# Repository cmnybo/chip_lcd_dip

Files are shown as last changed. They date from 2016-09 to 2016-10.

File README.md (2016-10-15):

# C.H.I.P. LCD Adapter & SPI Multiplexer

This DIP is compatible with the following touch screen LCD panels (resistive touch version only):

1. [4.3" 480x272](http://www.buydisplay.com/default/tft-4-3-inch-lcd-module-touchscreen-display-for-mp4-gps-480x272)
2. [5" 800x480](http://www.buydisplay.com/default/5-tft-lcd-display-module-wvga-800x480-high-resolution-for-mp4-gps)
3. [7" 800x480](http://www.buydisplay.com/default/7-tft-lcd-touch-screen-display-module-800x480-for-mp4-gps-tablet-pc)

## Features

* PWM controlled backlight driver
* 8 channel chip select multiplexer for SPI
* 34 pin gpio header that can be connected with old floppy drive cables
* Pin headers for the UART and power switch
* 5.5x2.5mm barrel jack to supply power (5V 2.5A)

The original design files for this board were created in [KiCAD](http://kicad-pcb.org/). <br/>
There are PDF copies of the schematic, PCB layout, and bill of materials in the "pdf" directory.<br/>
The "gerber" directory contains all of the files needed to have some boards made.<br/>
The device tree overlay, kernel patch, and EEPROM image are in the "source" directory.

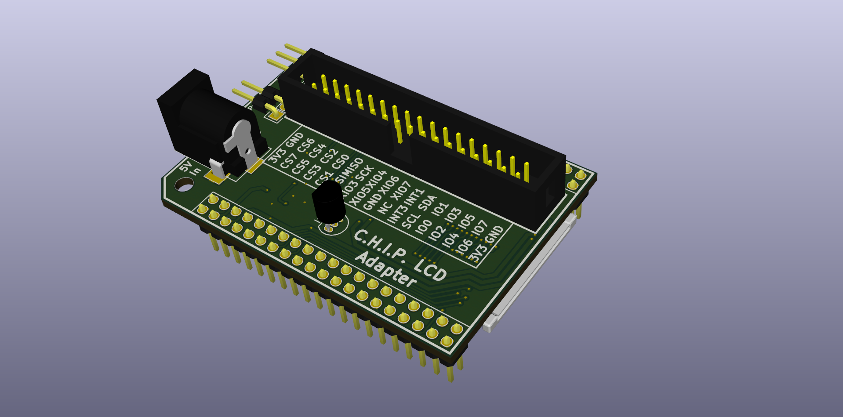
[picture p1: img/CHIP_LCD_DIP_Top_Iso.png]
3D Rendering of the DIP


## License
**This project is open source hardware.**

All files are licensed under a [Creative Commons Attribution-ShareAlike](https://creativecommons.org/licenses/by-sa/3.0) license.



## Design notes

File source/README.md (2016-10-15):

# Software

## Files
* lcd_panel.dts The device tree overlay source for this DIP
* dip-d653-1.dtbo The compiled device tree overlay for this dip
* er-tft050-3.patch The patch for the kernel driver to support the 5" & 7" LCDs
* lcd.img The EEPROM image for the DIP
* Linux_Kernel_4.4.11_Patched.tar.gz My custom kernel with the LCD patch already installed
* bl.sh A bash script to control the LCD backlight

## Installation
1. Install the patched kernel. 
2. Install the DTBO file. Run "`cp dip-d653-1.dtbo /lib/firmware/nextthingco/chip/early/`"
3. Flash lcd.img to the EEPROM. Run "`cat lcd.img > /sys/bus/w1/devices/2d-*/eeprom`"
4. Reboot C.H.I.P. It takes several seconds for the LCD to come on.
5. Calibrate the touch screen. 

## Touch Screen Calibration
You will probably need to connect a mouse until the tough screen is calibrated.<br/>
Install xinput_calibrator.<br/>
Run "`mkdir -p /etc/X11/xorg.conf.d/`" to create the directory for the calibration data.<br/>
Select "System > Calibrate Touchscreen" from the applications menu. <br/>
Follow the instructions, then paste its output in `/etc/X11/xorg.conf.d/99-calibration.conf`<br/>
Reboot or run "`systemctl restart lightdm`" to restart the X server.

You can add the following lines to the calibration file to enable right click emulation.<br/>
>
`Option	"EmulateThirdButton" "1"`<br/>
`Option	"EmulateThirdButtonTimeout" "750"`<br/>
`Option	"EmulateThirdButtonMoveThreshold" "30"`<br/>

## Controlling the backlight
Put the bl.sh script in a directory that's included in your $PATH variable.<br/>
Run `bl.sh` with the `--up` or `--dn` options to adjust the brightness.<br/>
Run `bl.sh` with the `--toggle` option to toggle the display on and off.<br/>
For easier control, you can add these to some shortcuts in the 
"Application Shortcuts" tab of the Keyboard settings window.

The system power management can automatically turn off the display when idle, 
but I have noticed some problems when turning the screen back on. If you have 
trouble with this, you can disable power management for the LCD in the 
"Power Manager" window.

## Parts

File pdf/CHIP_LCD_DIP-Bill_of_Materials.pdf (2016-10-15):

Bill of Materials

Page 1

Reference | Value | Manufacturer | Package | DigiKey | Quantity Notes
C1, C2, C7 | 0.1µF | Samsung | 0603 | 1276-1006-1-ND | 3
C3 | 1µF | Samsung | 0603 | 1276-6524-1-ND | 1
C4 | 10µF | Samsung | 0603 | 1276-1119-1-ND | 1
C5 | 10µF | Samsung | 0805 | 490-12538-1-ND | 1
C6 | 1µF | Samsung | 0603 | 1276-1860-1-ND | 1 Can be used for C3 as well
D1 | DB2J40700 Panasonic | SOD-323 | DB2J40700LCT-ND | 1
IC1 | 74LVC138 | NXP Semiconductors | 16-SOIC (3.90mm) 568-1577-5-ND | 1
IC2 | DS2431 | Maxim Integrated | TO-92-3 | DS2431+-ND | 1
IC3 | AP3032 | Diodes Incorporated | SOT-23-6 | AP3032KTR-G1DICT-ND | 1
IC4 | 74AHC1G08 NXP Semiconductors | SC-70-5 | 568-2501-1-ND | 1
L1 | 15µH | TDK | | 445-6598-1-ND | 1
P1 | C.H.I.P. | Sullins Connector Solutions | | S2011EC-20-ND | 220x2 Pin Male Headers
P2 | Power | CUI Inc. | 2.5x5.5mm | CP-002B-ND | 15.5x2.5mm Barrel Jack
P3 | Pwr SW | Harwin Inc. | | 952-2244-ND | 12 Pin Male Header (Right Angle)
P4 | UART | Harwin Inc. | | 952-2245-ND | 13 Pin Male Header (Right Angle)
P5 | LCD | TE Connectivity | | A100226CT-ND | 140 Pin Flat Flex 0.5mm Bottom Contacts
P6 | GPIO | On Shore Technology Inc. | | ED10528-ND | 117x2 Shrouded Male Header
R1 | 5.1Ω | Yageo | 0603 | 311-5.1GRCT-ND | 1 For 5” & 7” Panels (39mA backlight)
R1 | 15Ω | Yageo | 0603 | 311-15GRCT-ND | 1 For 4.3” Panel (13mA Backlight)
R2 | 4.7K | Yageo | 0603 | 311-4.7KGRCT-ND | 1

Notes
Capacitors can be substituted as long as the package, voltage, and capacitance is the same. Use X5R or X7R dielectric. Resistors can be substituted as long as the package and resistance are the same.
Cheap pin headers from eBay will work fine if you want to save some money. DigiKey is expensive for pin headers.
The LCD connector (P5) is already installed if you bought one of my boards.

R1 sets the backlight current. Current = 0.2/R1

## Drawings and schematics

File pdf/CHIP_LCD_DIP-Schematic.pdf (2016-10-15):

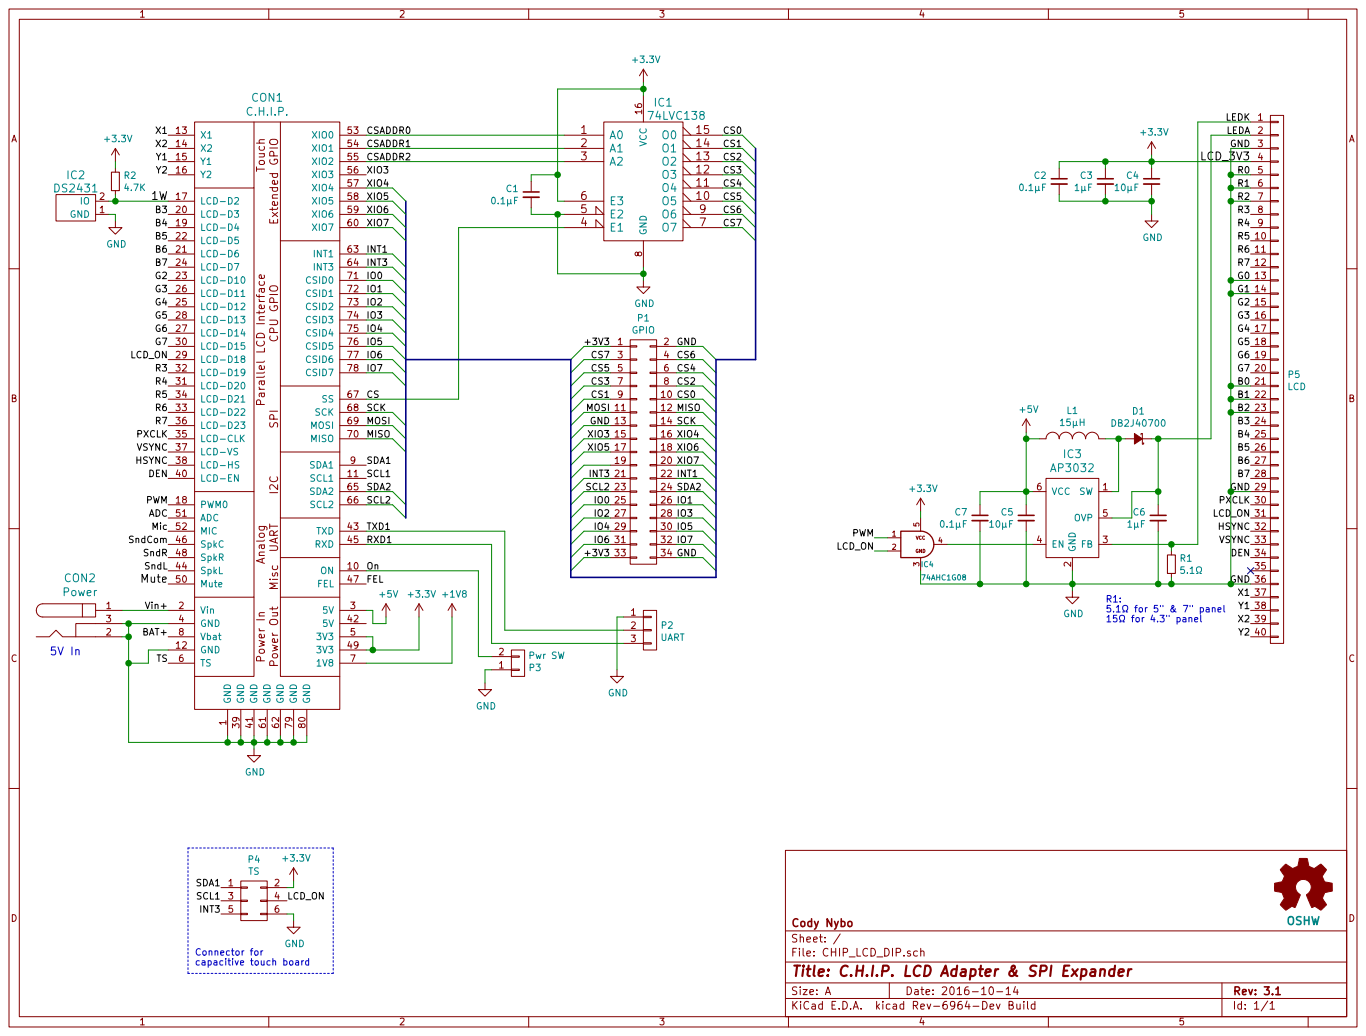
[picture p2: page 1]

File: CHIP_LCD_DIP.sch Sheet: / Cody Nybo Analog CPU GPIO Extended GPIO I2C Misc Parallel LCD Interface Power In Power Out SPI Touch UART GND

DEN
Vin+ PWM
ADC Mic SndL SndR

2 FB 3 EN 4 OVP 5 VCC 6

Connector for capacitive touch board

Id: 1/1 Title: C.H.I.P. LCD Adapter & SPI Expander

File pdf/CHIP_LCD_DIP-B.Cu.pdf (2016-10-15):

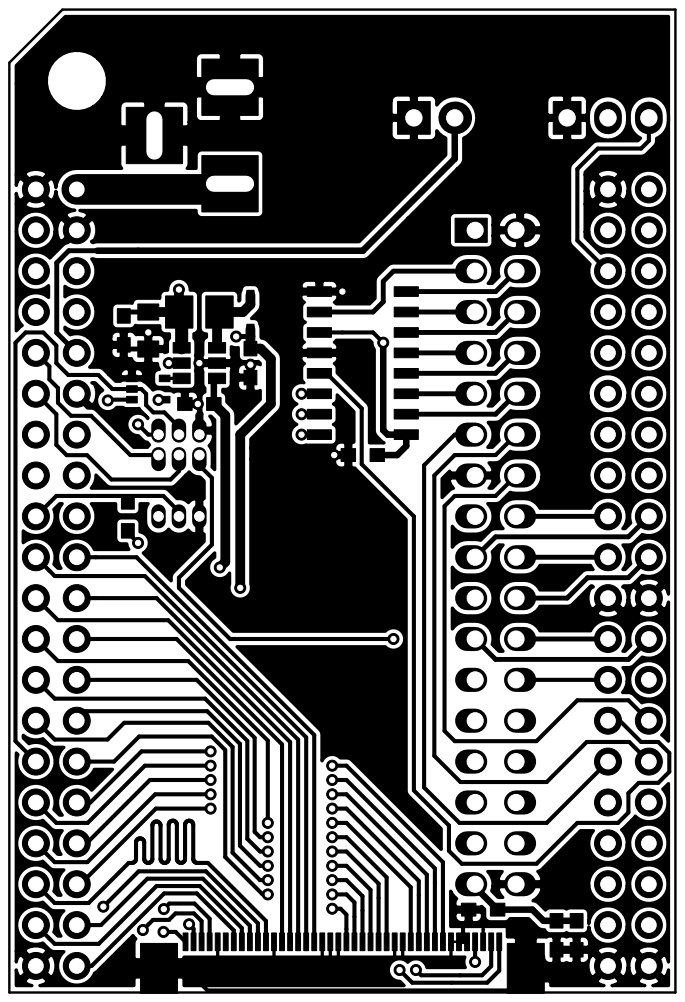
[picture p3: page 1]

File: CHIP_LCD_DIP.kicad_pcb Sheet: Cody Nybo

Id: 1/1 Title: C.H.I.P. LCD Adapter & SPI Expander

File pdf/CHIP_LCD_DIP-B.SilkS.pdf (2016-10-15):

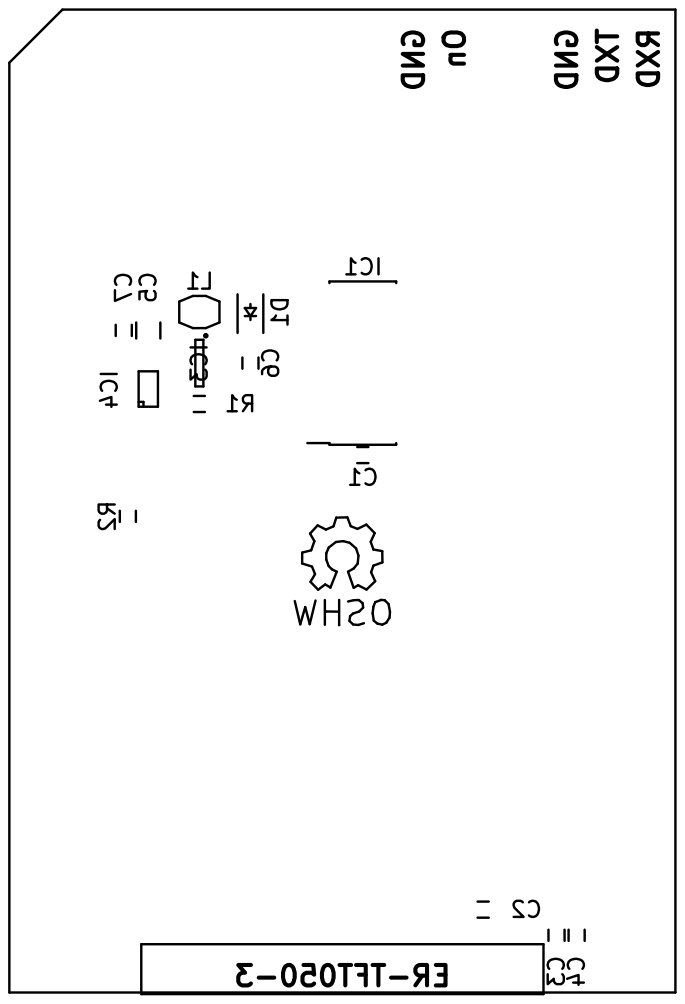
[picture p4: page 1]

Id: 1/1 Title: C.H.I.P. LCD Adapter & SPI Expander

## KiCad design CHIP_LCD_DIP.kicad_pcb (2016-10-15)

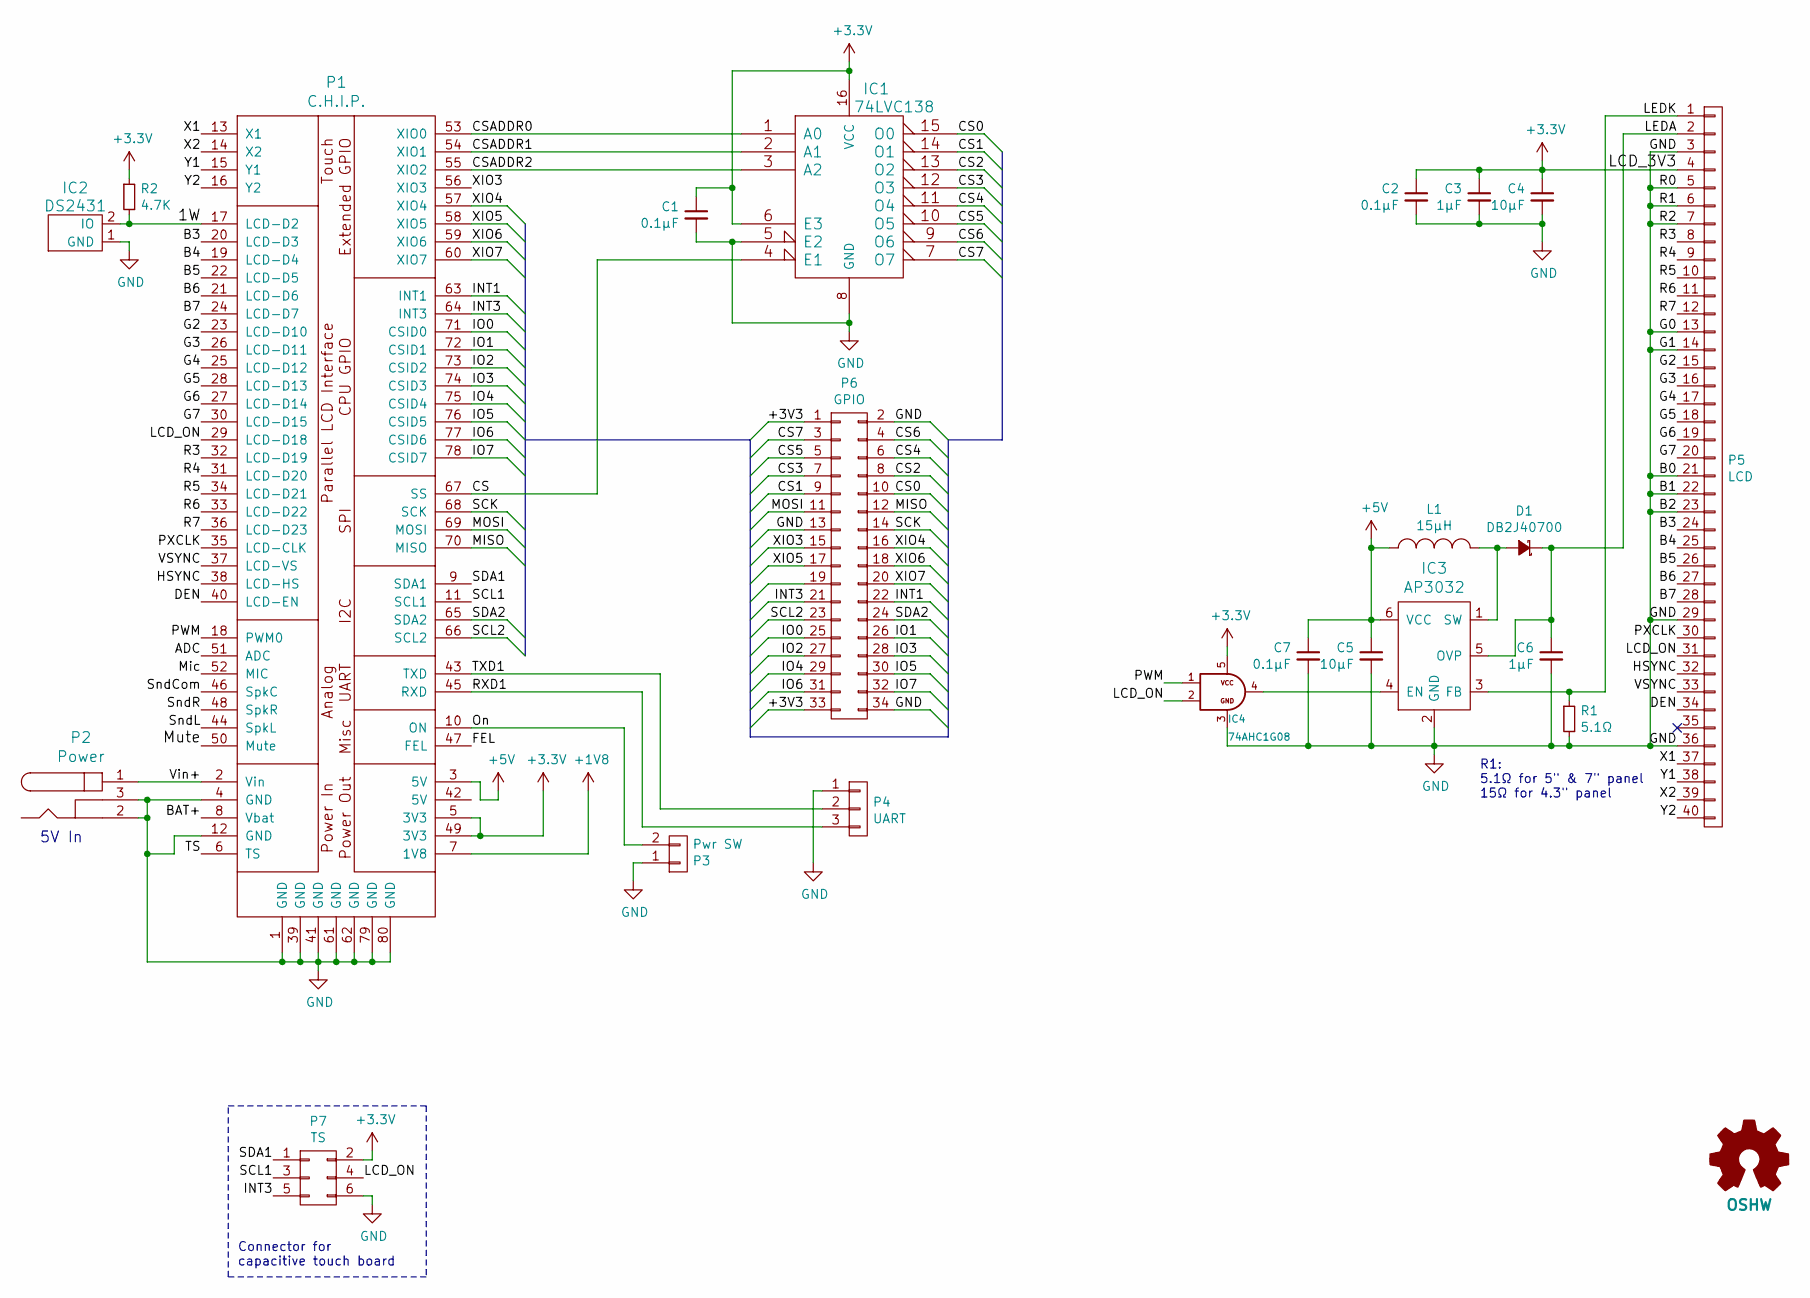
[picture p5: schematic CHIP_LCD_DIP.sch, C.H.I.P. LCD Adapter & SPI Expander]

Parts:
C1, C2, C7: 0.1µF; C_0603; Voltage 25V; Tolerance 10%; DigiKey 1276-1006-1-ND
C3: 1µF; C_0603; Voltage 16V; Tolerance 20%; DigiKey 1276-6524-1-ND
C4: 10µF; C_0603; Voltage 6.3V; Tolerance 20%; DigiKey 1276-1119-1-ND
C5: 10µF; C_0603; Voltage 6.3V; Tolerance 10%; DigiKey 490-12538-1-ND
C6: 1µF; C_0603; Voltage 50V; Tolerance 10%; DigiKey 1276-1860-1-ND
D1: DB2J40700; SOD-323; Voltage 40V; DigiKey DB2J40700LCT-ND
IC1: 74LVC138; SOIC-16_3.9x9.9mm_Pitch1.27mm; DigiKey 568-1577-5-ND
IC2: DS2431; TO-92_Inline_Narrow_Oval; DigiKey DS2431+-ND
IC3: AP3032; SOT-23-6; DigiKey AP3032KTR-G1DICT-ND
IC4: 74AHC1G08; SC-70-5; DigiKey 568-2501-1-ND
L1: 15µH; TDK_VLS-E-CA; Tolerance 20%; DigiKey 445-6598-1-ND
LOGO1: OSHW
P1: C.H.I.P.; CHIP_DIP
P2: Power; BARREL_JACK; DigiKey CP-002B-ND
P3: Pwr SW; Pin_Header_Straight_1x02; DigiKey 952-2244-ND
P4: UART; Pin_Header_Straight_1x03; DigiKey 952-2245-ND
P5: LCD; TE_40_PIN_LCD_Connector; DigiKey A100226CT-ND
P6: GPIO; vasch_strip_17x2; DigiKey ED10528-ND
P7: TS; 02x03_Header_0.05
R1: 5.1Ω; C_0603; Tolerance 5%; Voltage 75V; DigiKey 311-5.1GRCT-ND
R2: 4.7K; C_0603; Tolerance 5%; Voltage 75V; DigiKey 311-4.7KGRCT-ND

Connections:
+1V8: P1.7 (1V8)
+5V: C5.1, C7.1, IC3.6 (VCC), L1.1, P1.3 (5V)
/1W: IC2.2 (IO), P1.17 (LCD-D2), R2.2
/ADC: P1.51 (ADC)
/B3: P1.20 (LCD-D3), P5.24
/B4: P1.19 (LCD-D4), P5.25
/B5: P1.22 (LCD-D5), P5.26
/B6: P1.21 (LCD-D6), P5.27
/B7: P1.24 (LCD-D7), P5.28
/BAT+: P1.8 (Vbat)
/CS: IC1.4 (E1), P1.67 (SS)
/CS0: IC1.15 (O0), P6.10
/CS1: IC1.14 (O1), P6.9
/CS2: IC1.13 (O2), P6.8
/CS3: IC1.12 (O3), P6.7
/CS4: IC1.11 (O4), P6.6
/CS5: IC1.10 (O5), P6.5
/CS6: IC1.9 (O6), P6.4
/CS7: IC1.7 (O7), P6.3
/CSADDR0: IC1.1 (A0), P1.53 (XIO0)
/CSADDR1: IC1.2 (A1), P1.54 (XIO1)
/CSADDR2: IC1.3 (A2), P1.55 (XIO2)
/DEN: P1.40 (LCD-EN), P5.34
/FEL: P1.47 (FEL)
/G2: P1.23 (LCD-D10), P5.15
/G3: P1.26 (LCD-D11), P5.16
/G4: P1.25 (LCD-D12), P5.17
/G5: P1.28 (LCD-D13), P5.18
/G6: P1.27 (LCD-D14), P5.19
/G7: P1.30 (LCD-D15), P5.20
/HSYNC: P1.38 (LCD-HS), P5.32
/INT1: P1.63 (INT1), P6.22
/INT3: P1.64 (INT3), P6.21, P7.5
/IO0: P1.71 (CSID0), P6.25
/IO1: P1.72 (CSID1), P6.26
/IO2: P1.73 (CSID2), P6.27
/IO3: P1.74 (CSID3), P6.28
/IO4: P1.75 (CSID4), P6.29
/IO5: P1.76 (CSID5), P6.30
/IO6: P1.77 (CSID6), P6.31
/IO7: P1.78 (CSID7), P6.32
/LCD_ON: IC4.2, P1.29 (LCD-D18), P5.31, P7.4
/LEDA: C6.1, D1.1 (K), IC3.5 (OVP), P5.2
/LEDK: IC3.3 (FB), P5.1, R1.1
/MISO: P1.70 (MISO), P6.12
/MOSI: P1.69 (MOSI), P6.11
/Mic: P1.52 (MIC)
/Mute: P1.50 (Mute)
/On: P1.10 (ON), P3.2
/PWM: IC4.1, P1.18 (PWM0)
/PXCLK: P1.35 (LCD-CLK), P5.30
/R3: P1.32 (LCD-D19), P5.8
/R4: P1.31 (LCD-D20), P5.9
/R5: P1.34 (LCD-D21), P5.10
/R6: P1.33 (LCD-D22), P5.11
/R7: P1.36 (LCD-D23), P5.12
/RXD1: P1.45 (RXD), P4.3
/SCK: P1.68 (SCK), P6.14
/SCL1: P1.11 (SCL1), P7.3
/SCL2: P1.66 (SCL2), P6.23
/SDA1: P1.9 (SDA1), P7.1
/SDA2: P1.65 (SDA2), P6.24
/SndCom: P1.46 (SpkC)
/SndL: P1.44 (SpkL)
/SndR: P1.48 (SpkR)
/TS: P1.6 (TS)
/TXD1: P1.43 (TXD), P4.2
/VSYNC: P1.37 (LCD-VS), P5.33
/Vin+: P1.2 (Vin), P2.1
/X1: P1.13 (X1), P5.37
/X2: P1.14 (X2), P5.39
/XIO3: P1.56 (XIO3), P6.15
/XIO4: P1.57 (XIO4), P6.16
/XIO5: P1.58 (XIO5), P6.17
/XIO6: P1.59 (XIO6), P6.18
/XIO7: P1.60 (XIO7), P6.20
/Y1: P1.15 (Y1), P5.38
/Y2: P1.16 (Y2), P5.40
GND: C1.2, C2.2, C3.2, C4.2, C5.2, C6.2, C7.2, IC1.5 (E2), IC1.8 (GND), IC2.1 (GND), IC3.2 (GND), IC4.3, P1.1 (GND), P1.4 (GND), P1.12 (GND), P1.39 (GND), P1.41 (GND), P1.61 (GND), P1.62 (GND), P1.79 (GND), P1.80 (GND), P2.2, P2.3, P3.1, P4.1, P5.3, P5.5, P5.6, P5.7, P5.13, P5.14, P5.21, P5.22, P5.23, P5.29, P5.36, P6.2, P6.13, P6.34, P7.6, R1.2
unnamed: D1.2 (A), IC3.1 (SW), L1.2
unnamed: IC3.4 (EN), IC4.4

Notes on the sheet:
R1: 5.1Ω for 5" & 7" panel 15Ω for 4.3" panel
5V In
Connector for capacitive touch board

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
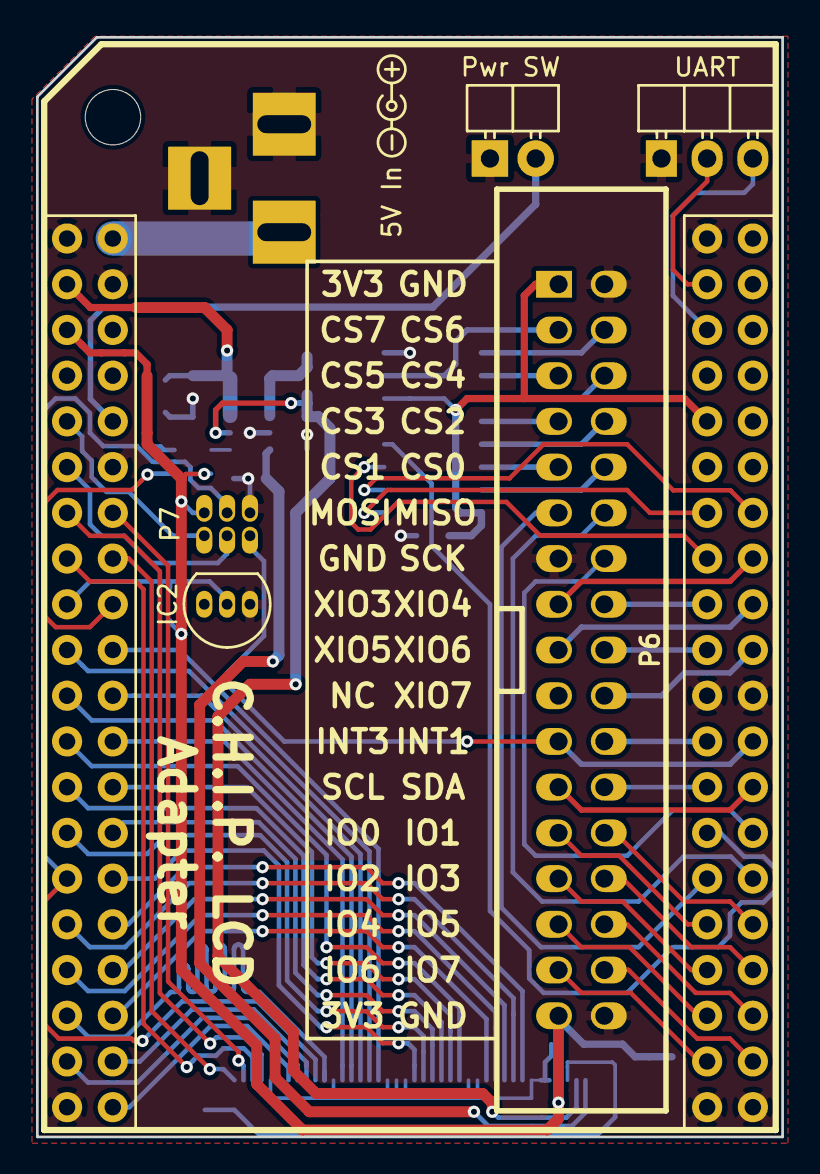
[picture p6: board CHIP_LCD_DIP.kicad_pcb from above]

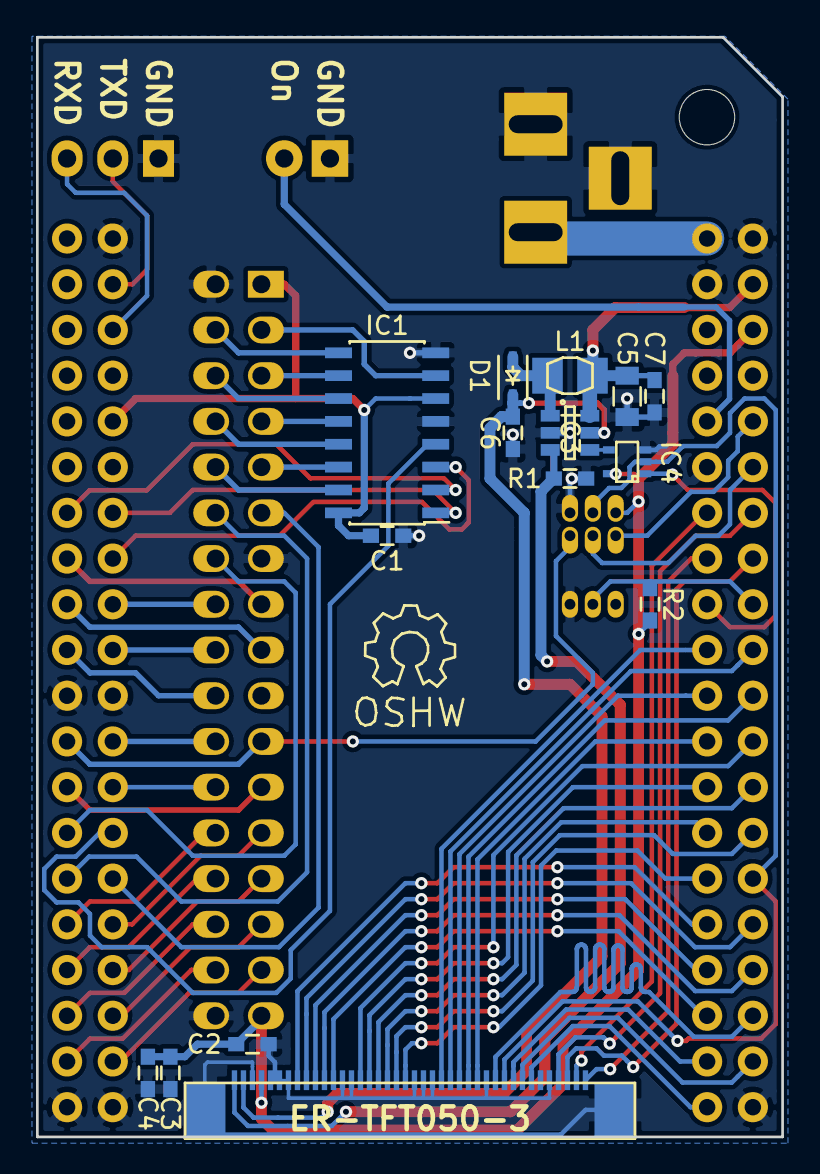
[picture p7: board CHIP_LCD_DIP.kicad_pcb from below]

Board: 2 copper layers, 41.4 x 61.1 mm, 22 parts (15 on the bottom side), 72 nets.

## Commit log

2016-09-01 Added gerber files
    [CHIP_LCD_DIP-B.Cu.gbl, CHIP_LCD_DIP-B.Mask.gbs, CHIP_LCD_DIP-B.SilkS.gbo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]
2016-09-02 Added connector to go to optional capacitive touch board.
    [CHIP_LCD_DIP-B.Cu.gbl, CHIP_LCD_DIP-B.Mask.gbs, CHIP_LCD_DIP-B.SilkS.gbo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]
2016-10-15 Updated files. Added source code. Added pdf copies of design files.
    [BOM.ods, CHIP_LCD_DIP.kicad_pcb, CHIP_LCD_DIP.sch]
2016-10-15 Updated device tree overlay
